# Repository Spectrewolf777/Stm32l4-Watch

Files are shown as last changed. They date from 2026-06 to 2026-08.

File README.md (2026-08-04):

## BLE Nrf52 code
https://github.com/Spectrewolf777/Nrf52-code-for-l4-watch

## Hardware Components

| Component | Part Number | Description / Function |
| :--- | :--- | :--- |
| **MCU** | `STM32L4P5CGU6` | Ultra-low-power ARM Cortex-M4 Microcontroller |
| **Wireless** | `NRF52805-CAAA-R` | Bluetooth Low Energy (BLE) 5.2 SoC |
| **PMIC / Charger** | `BQ25101YFPR` | Single-cell Li-Ion/Li-Pol battery charger |
| **Battery Protection** | `XB5350D0` | Integrated Lithium battery protection IC |
| **Fuel Gauge** | `MAX17048G+T10` | Ultra-low power ModelGauge Li+ battery fuel gauge |
| **Accelerometer** | `BMA400` | Ultra-low-power 3-axis accelerometer (pedometer/activity) |
| **IMU** | `LSM6DSV16XTR` | 6-axis IMU with embedded Machine Learning Core |
| **Magnetometer** | `LIS3MDLTR` | 3-axis digital magnetic sensor (compass) |
| **EEPROM** | `M24512-DFMC6TG` | 512-Kbit serial I2C EEPROM |
| **RTC** | `RV-3028-C7` | Ultra-clean, 1ppm high-stability real-time clock module |
| **Haptic Driver** | `DRV2605LYZFR` | ERM/LRA haptic driver with built-in library |
| **Humidity / Temp** | `HDC2010YPAR` | Low-power digital humidity and temperature sensor |
| **Barometer** | `BMP388` | High-performance digital barometric pressure sensor |
| **NAND Flash** | `XTSDG04GWSIGA` | Onboard high-density SPI flash storage |
| **Microphone** | `IM68D128BV01XTMA1` | High-performance digital PDM microphone |

# Hardware Open Source Design Location
https://oshwlab.com/moin0192837465/project_glmgovsw <------- Can be found here all files

# Display 
https://www.aliexpress.com/item/1005007293053050.html

## Project function
- Watch is fully configurable through usb c, can act as a keyboard, mouse , badusb and can communicate through commands.
- Can store audio recordings and activate audio recording with gestures.
- Track steps
- Time tracking and stopwatch function
- Link phone and watch through bluetooth to get other data link weather or whatever you want.
- Watch can be used in future to control custom project you make later as it has bluetooth and is open source and can be programmed later

## Application Scenarios
- **Hardware Hackers & Developers:** Because the watch acts as a BadUSB, keyboard, and mouse, it can be used for rapid payload deployment, IT security testing, or simply as a wearable presentation clicker.
- **Custom Home Automation:** Utilizing the nRF52 BLE chip, makers can pair the watch to Home Assistant or custom ESP32 nodes to control smart home devices directly from their wrist.
- **Everyday Fitness & Utilities:** With the onboard BMA400 and RTC, it serves as an everyday pedometer, stopwatch, and voice-recorder (saving directly to the NAND flash).

## Current Software Implementation

- **Dual USB Interface:** Configured via TinyUSB to expose both **CDC (Virtual COM Port)** for serial debugging which can accept commands and **Mass Storage Class (MSC)** for direct file access.
- **Storage Integration:** Connection to the onboard **Storage**, allowing the device to act as a standard USB flash drive when plugged into a host.
- **RTC** can set time and recieve time updating ui.
- **Motion & Orientation Tracking** - IMU to reconize when screen tilted and to count steps.

## Planned Software Features

- **RTC:** Need to setup timers to count down on ui.
- **Wireless Connectivity:** Integrate a **Bluetooth** stack to enable smartphone data syncing.
- Implement a digital **compass** for accurate heading and orientation sensing.
- **Motion & Orientation Tracking:** - adding more gestures to control microphone.
- act as a keyboard, mouse , badusb and can communicate through commands.
- link phone and watch through bluetooth to get other data link weather or whatever you want.
- Watch can be used in future to control custom project you make later as it has bluetooth and is open source and can be programmed later 
- store audio recordings and activate audio recording with gestures.

nnnn
Battery not soldered yet that why i am using usb as coding hasnt finished and wanted to do more current testing.

Untitled design


## Programming Instructions

This board can be programmed using one of two methods depending on your hardware setup and whether you need Bluetooth Low Energy (BLE) functionality.

- **Method 1 (Recommended): SWD Programmer**
  - Allows you to flash both the **STM32** and the **nRF52** microcontrollers for full functionality (including BLE).
  - Works with an **ST-Link** or **J-Link** (the **J-Link EDU Mini** is highly recommended as it natively supports both ecosystems).
  - Connection can be made via a Tag-Connect cable like the **TC2030-IDC-NL** (an adapter board may be required depending on your toolchain).

- **Method 2: USB-C DFU Bootloader**
  - Allows direct flashing over USB-C using an `.elf` file and **STM32CubeProgrammer**.
  - **Limitation:** This method **cannot** program the nRF52 chip, meaning you will not have BLE functionality out of the box. 
  - **Hardware Note:** If you are omitting BLE, you can completely disconnect the BLE circuit by desoldering the **0 $\Omega$ resistor** located in the BLE section of the board.

CNC Aluminum Case
## 

## Things to improve on next pcb design

- **Upgraded Architecture:** switch from the STM32L4 to the more powerful **STM32U5** advanced low-power states and maybe buck down to 1.8V instead of 3.3V.
- **High-Speed USB:** Upgrade the USB interface to **USB High-Speed (HS)** for faster write and read speeds.
- **Stereo Audio:** Replace the current mono microphone setup with a **stereo microphone**.
- **Storage Expansion:** Upgrade the onboard flash storage to a **larger capacity** .
- **NRF53:** Allows ble headphones to connect in order to send audio from sd flash or microphones to headphones.
- **Screen:** AMOLED Screen.
- **Sensor:** Add light and any other missing sensors.
- **XIP:** More storage for ui.
- **GPS:** Allows coordinates but also better tracking of activities like running and maybe add similar to google maps but locally no internet. Can also allow time to sync directly UTC from satellites rather then phone.
- **Quality of life:** add a coin cell for rtc backup to retain battery life longer. Better battery mounting position. 
- **Form Factor & Enclosure Optimization:** - Reduce the overall PCB diameter from **44mm down to 40mm**.
  - Relocate and fix the **battery positioning**.

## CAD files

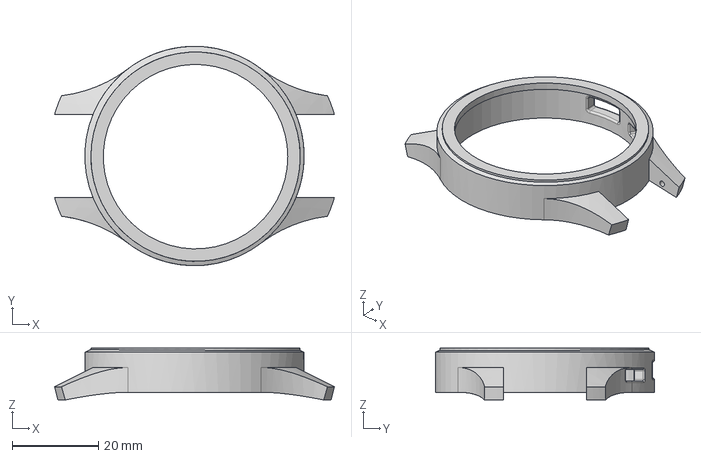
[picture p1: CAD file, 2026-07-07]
watchCase3dPrint0.2mmtolerance.step
64.8 x 50.8 x 12.0 mm

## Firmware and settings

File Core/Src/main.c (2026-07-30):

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
/* Includes ------------------------------------------------------------------*/
#include "main.h"
#include "dma.h"
#include "i2c.h"
#include "sdmmc.h"
#include "spi.h"
#include "usart.h"
#include "usb_otg.h"
#include "gpio.h"

/* USER CODE BEGIN Includes */
#include <stdio.h>
#include "GUI_Paint.h"
#include "fonts.h"
#include "image.h"
#include "LCD_Test.h"
#include "DEV_Config.h"
#include "tusb.h"
#include "rv_3028_c7.h"
#include "lv_port_disp.h"
#include "lvgl/examples/anim/lv_example_anim.h"
#include "UI/ui.h"
#include "serial_cmd.h"
#include "lsm6dsv16x_stepcounter.h"
#include "lsm6dsv16x_reg.h"
#include "wrist_wake.h"
#include "rtc_tasks.h"
#include "uart_cmd.h"

/* USER CODE END Includes */

/* USER CODE BEGIN PTD */
rv3028_handle_t rtc_handle;        /* RV-3028-C7 RTC handle */

/* USER CODE END PTD */


/* USER CODE BEGIN PV */
extern I2C_HandleTypeDef hi2c1; // I2C handle
extern UART_HandleTypeDef huart1;
uint32_t last_rtc_request_time = 0;
bool displayOn = false;
uint32_t display_turn_on_time = 0;

// Lookup table for 3-letter day names (1 = Monday, 7 = Sunday)
const char* days_of_week[] = { "", "Mon", "Tue", "Wed", "Thu", "Fri", "Sat", "Sun" };


#define RX_RING_BUFFER_SIZE 256

volatile uint8_t rx_buffer[RX_RING_BUFFER_SIZE];
volatile uint16_t rx_head = 0;
volatile uint16_t rx_tail = 0;


uint8_t uart1_rx_byte;

// Flags 
volatile bool rtc_interrupt_fired = false;
volatile bool rtc_read_complete = false;
#define STEP_UPDATE_INTERVAL_MS   1000U   /* how often to poll/refresh ui_steps */

bool StepCounter_CheckWristTilt(void);
void StepCounter_IRQHandler(void);



/* USER CODE END PV */

void SystemClock_Config(void);
/* USER CODE BEGIN 0 */

void I2C_Scanner(I2C_HandleTypeDef *hi2c) {
    printf("Starting I2C Scanner...\r\n");
    fflush(stdout);
    tud_task();

    HAL_StatusTypeDef res;
    for (uint8_t i = 0; i < 128; i++) {
        res = HAL_I2C_IsDeviceReady(hi2c, (uint16_t)(i << 1), 3, 100);
        if (res == HAL_OK) {
            printf("Device found at address: 0x%02X\r\n", i);
            fflush(stdout);
        }
        tud_task();  
    }
    printf("Scanner Complete.\r\n");
    fflush(stdout);
    tud_task();
}


void process_uart_to_usb(void)
{
    // Check if we have data and USB CDC is ready
    if (rx_head != rx_tail && tud_cdc_connected()) {
        uint32_t available_usb_space = tud_cdc_write_available();
        
        if (available_usb_space > 0) {
            uint8_t temp_buf[64];
            uint32_t count = 0;

            // Pull data from ring buffer
            while (rx_head != rx_tail && count < sizeof(temp_buf) && count < available_usb_space) {
                temp_buf[count++] = rx_buffer[rx_tail];
                rx_tail = (rx_tail + 1) % RX_RING_BUFFER_SIZE;
            }

            // Transmit over USB
            if (count > 0) {
                tud_cdc_write(temp_buf, count);
                tud_cdc_write_flush(); 
            }
        }
    }
}


void USB_Print(const char *format, ...)
{
    // Don't try to send if the USB isn't connected
    if (!tud_cdc_connected()) {
        return; 
    }

    char buffer[128]; // Adjust buffer size if you plan to send very long strings
    va_list args;
    
    va_start(args, format);
    int len = vsnprintf(buffer, sizeof(buffer), format, args);
    va_end(args);

    if (len > 0) {
        tud_cdc_write(buffer, len);
        tud_cdc_write_flush(); // Force the data to send immediately
    }
}

void USB_Printf(const char *format, ...)
{
    if (!tud_cdc_connected()) return;

    char buffer[128]; // Temporary buffer 
    
    va_list args;
    va_start(args, format);
    vsnprintf(buffer, sizeof(buffer), format, args);
    va_end(args);

    tud_cdc_write_str(buffer);
    tud_cdc_write_flush();
}




/* USER CODE END 0 */

/**
  * @brief  The application entry point.
  * @retval int
  */
int main(void)
{

  /* MCU Configuration--------------------------------------------------------*/

  /* Reset of all peripherals, Initializes the Flash interface and the Systick. */
  HAL_Init();

  /* Configure the system clock */
  SystemClock_Config();

  /* Initialize all configured peripherals */
  MX_GPIO_Init();
  MX_DMA_Init();
  MX_I2C2_Init();
  MX_SPI2_Init();
  MX_SDMMC2_SD_Init();
  MX_I2C1_Init();
  MX_USB_OTG_FS_PCD_Init();
  MX_USART1_UART_Init();
  /* USER CODE BEGIN 2 */
  HAL_GPIO_WritePin(BL_GPIO_Port, BL_Pin, GPIO_PIN_RESET);
  HAL_UART_Receive_IT(&huart1, &uart1_rx_byte, 1);

  UART_Cmd_Init(&huart1);

  lv_init();
  lv_port_disp_init();
  //lv_example_anim_2();
  ui_init();
  uint32_t last_step_update_time = 0;
  rv3028_init(&rtc_handle, &hi2c1); // 
  bool step_sensor_ok = StepCounter_Init(&hi2c1);

  if (!step_sensor_ok) {

    lv_label_set_text(ui_steps, "--");
  }

  WristWake_Init(&hi2c1);


  // Set the initial time in your SquareLine image)
  rv3028_time_t initial_time = {
      .seconds = 0,
      .minutes = 33,
      .hours = 13, // 1:33 PM (using 24-hour format internally)
      .weekday = 2,
      .date = 7,
      .month = 7,
      .year = 26
  };
  rv3028_set_time(&rtc_handle, &initial_time);


  tusb_rhport_init_t dev_init = {
    .role = TUSB_ROLE_DEVICE,
    .speed = TUSB_SPEED_FULL
  };

  tusb_init(0, &dev_init);

  uint32_t start_time = HAL_GetTick();
  while (!tud_cdc_connected() && (HAL_GetTick() - start_time < 2000)) {
      tud_task(); // Keep processing USB events while waiting
  }
  
  char init_time_buf[16];
  uint8_t init_hour = initial_time.hours % 12;
  if (init_hour == 0) init_hour = 12;
  snprintf(init_time_buf, sizeof(init_time_buf), "%d:%02d", init_hour, initial_time.minutes);
  lv_label_set_text(ui_Time, init_time_buf);
  USB_Print("testing...\r\n");
  





    
  /* USER CODE END 2 */

  /* Infinite loop */
  /* USER CODE BEGIN WHILE */
  while (1)
  {
    /* USER CODE END WHILE */

    /* USER CODE BEGIN 3 */
    tud_task();
    lv_timer_handler();
    Process_Serial_Commands();
    Process_UART_Commands();   // nRF52 UART commands
    process_uart_to_usb();
    rtc_tasks(&rtc_handle); // Entire wrist-wake, RTC update, and  display timer logic 

    if (step_sensor_ok && (HAL_GetTick() - last_step_update_time >= STEP_UPDATE_INTERVAL_MS)) {
      last_step_update_time = HAL_GetTick();
      lv_label_set_text_fmt(ui_steps, "%u", StepCounter_GetSteps());
        const char *current_text = lv_label_get_text(ui_Time);
        strcpy(init_time_buf, current_text);
        // Send your text with a newline
        USB_Printf("current time: %s\r\n", current_text);
    }

  



  }
  /* USER CODE END 3 */
}

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
/* USER CODE BEGIN 4 */
// STM32 EXTI Callback - Fires when the rtc_int pin changes state
void HAL_GPIO_EXTI_Callback(uint16_t GPIO_Pin)
{
    // Check if the pin that triggered the interrupt is your rtc_int pin
    if (GPIO_Pin == rtc_int_Pin) { 
        rtc_interrupt_fired = true;
    }

    if (GPIO_Pin == IMU_INT1_Pin) {   
      
      WristWake_OnExti();
      USB_Print("set...\r\n");
    }

   
  
    
}

// I2C Rx Complete Callback - Fires when the background time read is done
void HAL_I2C_MasterRxCpltCallback(I2C_HandleTypeDef *hi2c)
{
    if (hi2c->Instance == I2C1) { 
        rtc_read_complete = true;
    }

    

    

}



void HAL_UART_RxCpltCallback(UART_HandleTypeDef *huart)
{
    // Make sure the interrupt is coming from UART1
    if (huart->Instance == USART1) {
        
        // COMMAND PARSER!
        UART_Cmd_FeedByte(uart1_rx_byte);
        
        // existing USB pass-through logic
        uint16_t next_head = (rx_head + 1) % RX_RING_BUFFER_SIZE;
        if (next_head != rx_tail) {
            rx_buffer[rx_head] = uart1_rx_byte;
            rx_head = next_head;
        }
        
        // Re-arm the interrupt
        HAL_UART_Receive_IT(&huart1, &uart1_rx_byte, 1);
    }
}


/* USER CODE END 4 */
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


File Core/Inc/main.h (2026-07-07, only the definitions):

#define rtc_int_Pin GPIO_PIN_13
#define rtc_int_GPIO_Port GPIOC
#define rtc_int_EXTI_IRQn EXTI15_10_IRQn
#define DisplayEnable_Pin GPIO_PIN_0
#define DisplayEnable_GPIO_Port GPIOA
#define BL_Pin GPIO_PIN_2
#define BL_GPIO_Port GPIOA
#define IMU_INT1_Pin GPIO_PIN_3
#define IMU_INT1_GPIO_Port GPIOA
#define IMU_INT1_EXTI_IRQn EXTI3_IRQn
#define TP_RST_Pin GPIO_PIN_4
#define TP_RST_GPIO_Port GPIOA
#define TP_INT_Pin GPIO_PIN_0
#define TP_INT_GPIO_Port GPIOB
#define TP_INT_EXTI_IRQn EXTI0_IRQn
#define CS_Pin GPIO_PIN_2
#define CS_GPIO_Port GPIOB
#define RST_Pin GPIO_PIN_8
#define RST_GPIO_Port GPIOA
#define DC_Pin GPIO_PIN_10
#define DC_GPIO_Port GPIOA
#define SDEnable_Pin GPIO_PIN_15
#define SDEnable_GPIO_Port GPIOA

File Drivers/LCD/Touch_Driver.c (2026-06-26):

/*****************************************************************************
* | File      	:   Touch_1IN28.c
* | Author      :   Waveshare team
* | Function    :   Hardware underlying interface
* | Info        :
*                Used to shield the underlying layers of each master
*                and enhance portability
*----------------
* |	This version:   V1.0
* | Date        :   2022-12-02
* | Info        :   Basic version
*
******************************************************************************/
#include "Touch_Driver.h"

extern Touch_1IN28_XY XY;
/******************************************************************************
function :	read ID 读取ID
parameter:  CST816T : 0xB5
******************************************************************************/
UBYTE Touch_1IN28_WhoAmI()
{

    if (I2C_Read_Byte(0xA7) == 0xB5)
        return true;
    else
        return false;
}

/******************************************************************************
function :	reset touch 复位触摸
parameter:
******************************************************************************/
void Touch_1IN28_Reset()
{
    DEV_Digital_Write(DEV_TP_RST_PIN, 0);
    DEV_Delay_ms(100);
    DEV_Digital_Write(DEV_TP_RST_PIN, 1);
    DEV_Delay_ms(100);
}

/******************************************************************************
function :	Read software version number 读取软件版本号
parameter:
******************************************************************************/
UBYTE Touch_1IN28_Read_Revision()
{
    return I2C_Read_Byte(0xA9);
}

/******************************************************************************
function :	exit sleep mode 退出休眠模式
parameter:
******************************************************************************/
void Touch_1IN28_Stop_Sleep()
{
    I2C_Write_Byte(DisAutoSleep,0x01);
}

/******************************************************************************
function :	Set touch mode 设置触摸模式
parameter:
        mode = 0 gestures mode
        mode = 1 point mode
        mode = 2 mixed mode
******************************************************************************/
void Touch_1IN28_Set_Mode(UBYTE mode)
{
    if (mode == 1)
    {
        I2C_Write_Byte(IrqCtl,0X41);
        I2C_Write_Byte(NorScanPer,0X01);//Normal fast detection cycle unit 10ms
        I2C_Write_Byte(IrqPluseWidth,0x1c); //Interrupt low pulse output width 1.5MS
    }
    else if(mode == 2)
        I2C_Write_Byte(IrqCtl,0X71);
    else
        {
            I2C_Write_Byte(IrqCtl,0X11);
            I2C_Write_Byte(NorScanPer,0X01);
            I2C_Write_Byte(IrqPluseWidth,0x1c);//中断低脉冲输出宽度 1.5MS
            I2C_Write_Byte(MotionMask,EnDClick);//Enable double-tap mode
        }

}

/******************************************************************************
function :	wake up touchscreen 唤醒触摸屏
parameter:
******************************************************************************/
void Touch_1IN28_Wake_up()
{
    DEV_Digital_Write(DEV_TP_RST_PIN, 0);
    DEV_Delay_ms(10);
    DEV_Digital_Write(DEV_TP_RST_PIN, 1);
    DEV_Delay_ms(50);
    I2C_Write_Byte(0xFE,0x01);
}


/******************************************************************************
function :	screen initialization 屏幕初始化
parameter:
******************************************************************************/
UBYTE Touch_1IN28_init(UBYTE mode)
{
    UBYTE bRet,Rev;
    Touch_1IN28_Reset();
		while(1)
				{
					bRet = Touch_1IN28_WhoAmI();

					if (bRet)
					{
							printf("Success:Detected CST816T.\r\n");
							Rev = Touch_1IN28_Read_Revision();
							printf("CST816T Revision = %d\r\n",Rev);
							Touch_1IN28_Stop_Sleep();
						break;
					}
					else
					{
						HAL_Delay(10);
						MX_I2C2_Init();
						printf("Error: Not Detected CST816T.\r\n");
					}
				}
    XY.mode = mode;
    Touch_1IN28_Set_Mode(mode);

    XY.x_point = 0;
    XY.y_point = 0;
    return true;
}

/******************************************************************************
function :	Get the corresponding point coordinates 获取对应的点坐标
parameter:
******************************************************************************/
Touch_1IN28_XY Touch_1IN28_Get_Point(void)
{
    UBYTE data[4];
    I2C_Read_nByte(0x03, data, 4);

    XY.x_point = ((data[0] & 0x0f)<<8) + data[1];
    XY.y_point = ((data[2] & 0x0f)<<8) + data[3];
    
    return XY;
}

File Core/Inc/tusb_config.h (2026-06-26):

/*
 * The MIT License (MIT)
 *
 * Copyright (c) 2019 Ha Thach (tinyusb.org)
 *
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
 */

#ifndef TUSB_CONFIG_H_
#define TUSB_CONFIG_H_

#include "tusb_option.h"
#ifdef __cplusplus
 extern "C" {
#endif

//--------------------------------------------------------------------+
// Board Specific Configuration
//--------------------------------------------------------------------+

// RHPort number used for device can be defined by board.mk, default to port 0
#ifndef BOARD_TUD_RHPORT
#define BOARD_TUD_RHPORT      0
#endif

// RHPort max operational speed can defined by board.mk
#ifndef BOARD_TUD_MAX_SPEED
#define BOARD_TUD_MAX_SPEED   OPT_MODE_DEFAULT_SPEED
#endif

//--------------------------------------------------------------------
// Common Configuration
//--------------------------------------------------------------------

// defined by compiler flags for flexibility

#define CFG_TUSB_MCU OPT_MCU_STM32L4
#define CFG_TUSB_RHPORT0_MODE (OPT_MODE_DEVICE | OPT_MODE_FULL_SPEED)

#ifndef CFG_TUSB_MCU
#error CFG_TUSB_MCU must be defined
#endif

#ifndef CFG_TUSB_OS
#define CFG_TUSB_OS           OPT_OS_NONE
#endif

#ifndef CFG_TUSB_DEBUG
#define CFG_TUSB_DEBUG        0
#endif

// Enable Device stack
#define CFG_TUD_ENABLED       1

// Default is max speed that hardware controller could support with on-chip PHY
#define CFG_TUD_MAX_SPEED     BOARD_TUD_MAX_SPEED

/* USB DMA on some MCUs can only access a specific SRAM region with restriction on alignment.
 * Tinyusb use follows macros to declare transferring memory so that they can be put
 * into those specific section.
 * e.g
 * - CFG_TUSB_MEM SECTION : __attribute__ (( section(".usb_ram") ))
 * - CFG_TUSB_MEM_ALIGN   : __attribute__ ((aligned(4)))
 */
#ifndef CFG_TUSB_MEM_SECTION
#define CFG_TUSB_MEM_SECTION
#endif

#ifndef CFG_TUSB_MEM_ALIGN
#define CFG_TUSB_MEM_ALIGN    __attribute__ ((aligned(4)))
#endif

//--------------------------------------------------------------------
// DEVICE CONFIGURATION
//--------------------------------------------------------------------

#ifndef CFG_TUD_ENDPOINT0_SIZE
#define CFG_TUD_ENDPOINT0_SIZE   64
#endif

//------------- CLASS -------------//
#define CFG_TUD_CDC              1
#define CFG_TUD_MSC              1
#define CFG_TUD_HID              0
#define CFG_TUD_MIDI             0
#define CFG_TUD_VENDOR           0

#define CFG_TUD_CDC_NOTIFY        1 // Enable use of notification endpoint

// CDC FIFO size of TX and RX
#define CFG_TUD_CDC_RX_BUFSIZE   (TUD_OPT_HIGH_SPEED ? 512 : 64)
#define CFG_TUD_CDC_TX_BUFSIZE   (TUD_OPT_HIGH_SPEED ? 512 : 64)

// CDC Endpoint transfer buffer size, default to max bulk packet size (HS 512, FS 64). Larger is faster.
// Larger RX_EPSIZE requires CFG_TUD_CDC_RX_NEED_ZLP = 1 and host ZLP support
#define CFG_TUD_CDC_RX_EPSIZE  (TUD_OPT_HIGH_SPEED ? 512 : 64)
#define CFG_TUD_CDC_TX_EPSIZE  (TUD_OPT_HIGH_SPEED ? 512 : 64)

// MSC Buffer size of Device Mass storage
#define CFG_TUD_MSC_EP_BUFSIZE   16384

#ifdef __cplusplus
 }
#endif

#endif /* TUSB_CONFIG_H_ */

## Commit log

2026-07-07 Update STM32L4 code, added walking steps, tilt wrist code with intention to wakeup display using it later, watch can now talk through serial command and accept commands, updated UI to look better and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
2026-07-07 RTC functions and display day and time keep track of time cleaned up main function
2026-07-18 added BLE code uart commands and some ui updates
2026-11-07 Very large update, added compass, timers , multiple screens , touch to wake and recording voice and saving to sd card
2026-11-09 Add on-device sound alerts for deaf and hard-of-hearing users
    Detects smoke and CO alarms, door knocks, doorbells and sirens on the
    STM32L4P5, and alerts with vibration and an on-screen message.
    - Int8 CNN (5 classes) on log-mel features, plus a rule-based smoke (T3)
    and CO (T4) beep-pattern detector
    - Mic shared between the recorder and the detectors
    - Sound page, alert popup, Voice page training labels, -ai serial command
    - training/: training code using only CC0/CC-BY and synthetic audio,
    with per-clip attribution
    - MIT (code) and CERN-OHL-P-2.0 (hardware) licences, THIRD_PARTY.md
    ST's proprietary AI runtime and generated network code are not included;
    tools/update_model.sh creates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

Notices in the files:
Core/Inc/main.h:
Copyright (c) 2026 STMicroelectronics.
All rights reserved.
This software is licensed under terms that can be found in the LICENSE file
